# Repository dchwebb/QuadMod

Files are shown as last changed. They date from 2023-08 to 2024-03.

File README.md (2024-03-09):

# Quadmod
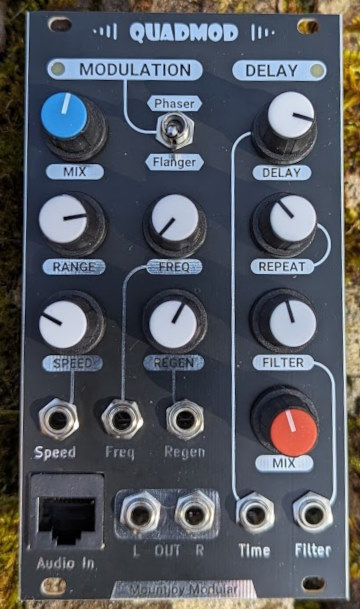
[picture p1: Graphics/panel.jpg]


Quadmod
--------

Quadmod is a Eurorack modular four channel effect module. A modulation section allows either phasing or flanging followed by a delay. As part of the Mountjoy Modular polyphonic range the module uses a series of intermodulation paths to convert a four channel input to a stereo output.

### Phaser
The phaser uses 4 (configurable up to 16) all pass filters to create the phasing effect. Each channel's all pass filter is 45° out of phase with the last. The regeneration (feedback) control progressively mixes one channel to the next to widen the stereo spectrum.

### Flanger
The flanger uses multiple short modulated delays to create a flanger/chorus effect. The delay times are modulated with a 45° phase shift from channel to channel. A wide option (on by default) mixes a further 180° phase shifted version of each channel's signal to the next channel.

Technical
---------

Quadmod uses an STM32563 microcontroller which controls a four channel Audio Codec (AsahiKasei AK4619) using SPI for configuration and SAI (Serial Ausio Interface) peripheral to manage the 4 in and 4 out I2S audio streams. The microcontroller reads the front panel controls with internal 12 bit ADCs.

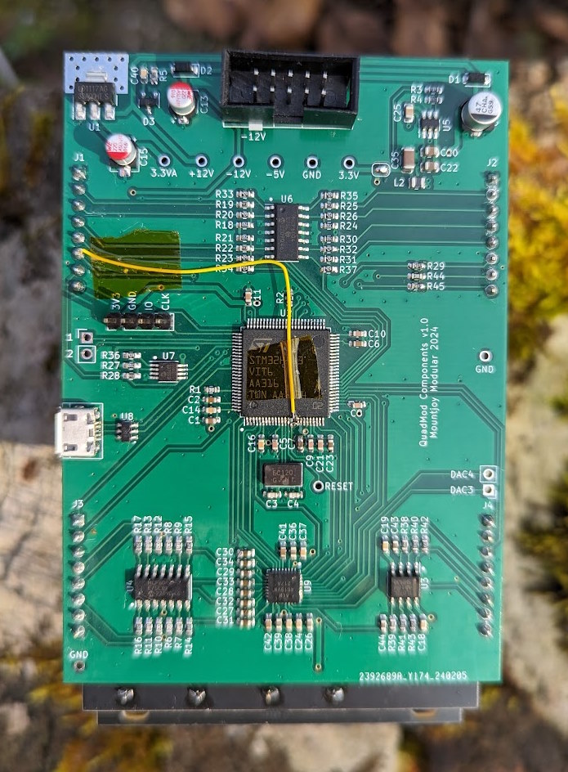
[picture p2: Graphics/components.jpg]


A USB socket is provided for serial configuration and a web editor using WebSerial provides a UI for editing settings. Three LEDs are controlled with PWM from the MCU to indicate modulation LFO rates and delay times.

Construction is a sandwich of three PCBs with a component board, a controls board and a panel. PCBs designed in Kicad v7.

[Components schematic](https://raw.githubusercontent.com/dchwebb/Quadmod/master/Hardware/Quadmod_Components.pdf)

[Controls schematic](https://raw.githubusercontent.com/dchwebb/Quadmod/master/Hardware/Quadmod_Controls.pdf)

In addition the the Eurorack +/-12V rails (which have polarity protection and filtering) a digital 3.3v rail is supplied using a TI TPS561201 and analog 3.3v is generated with an LM1117-3.3.

Errata
------

Version 1 of the component PCB had microcontroller pins PC0 (SAI2_SD_A) and PC1 (DLY_TIME_POT) flipped.

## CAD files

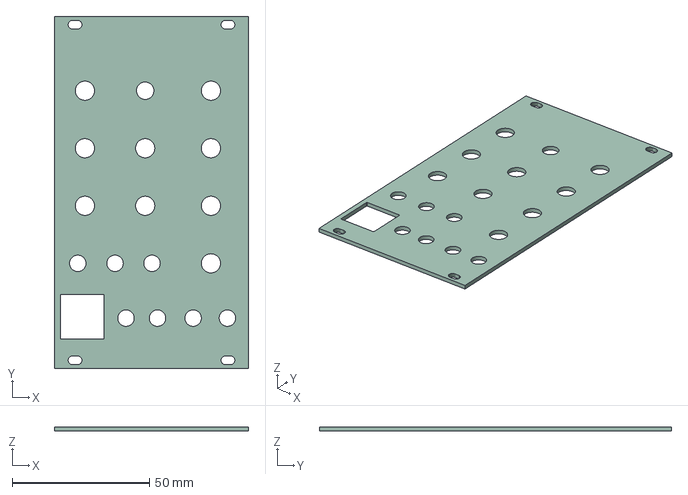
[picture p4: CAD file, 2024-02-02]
Hardware/QuadMod_Panel.step
70.8 x 128.5 x 1.60 mm

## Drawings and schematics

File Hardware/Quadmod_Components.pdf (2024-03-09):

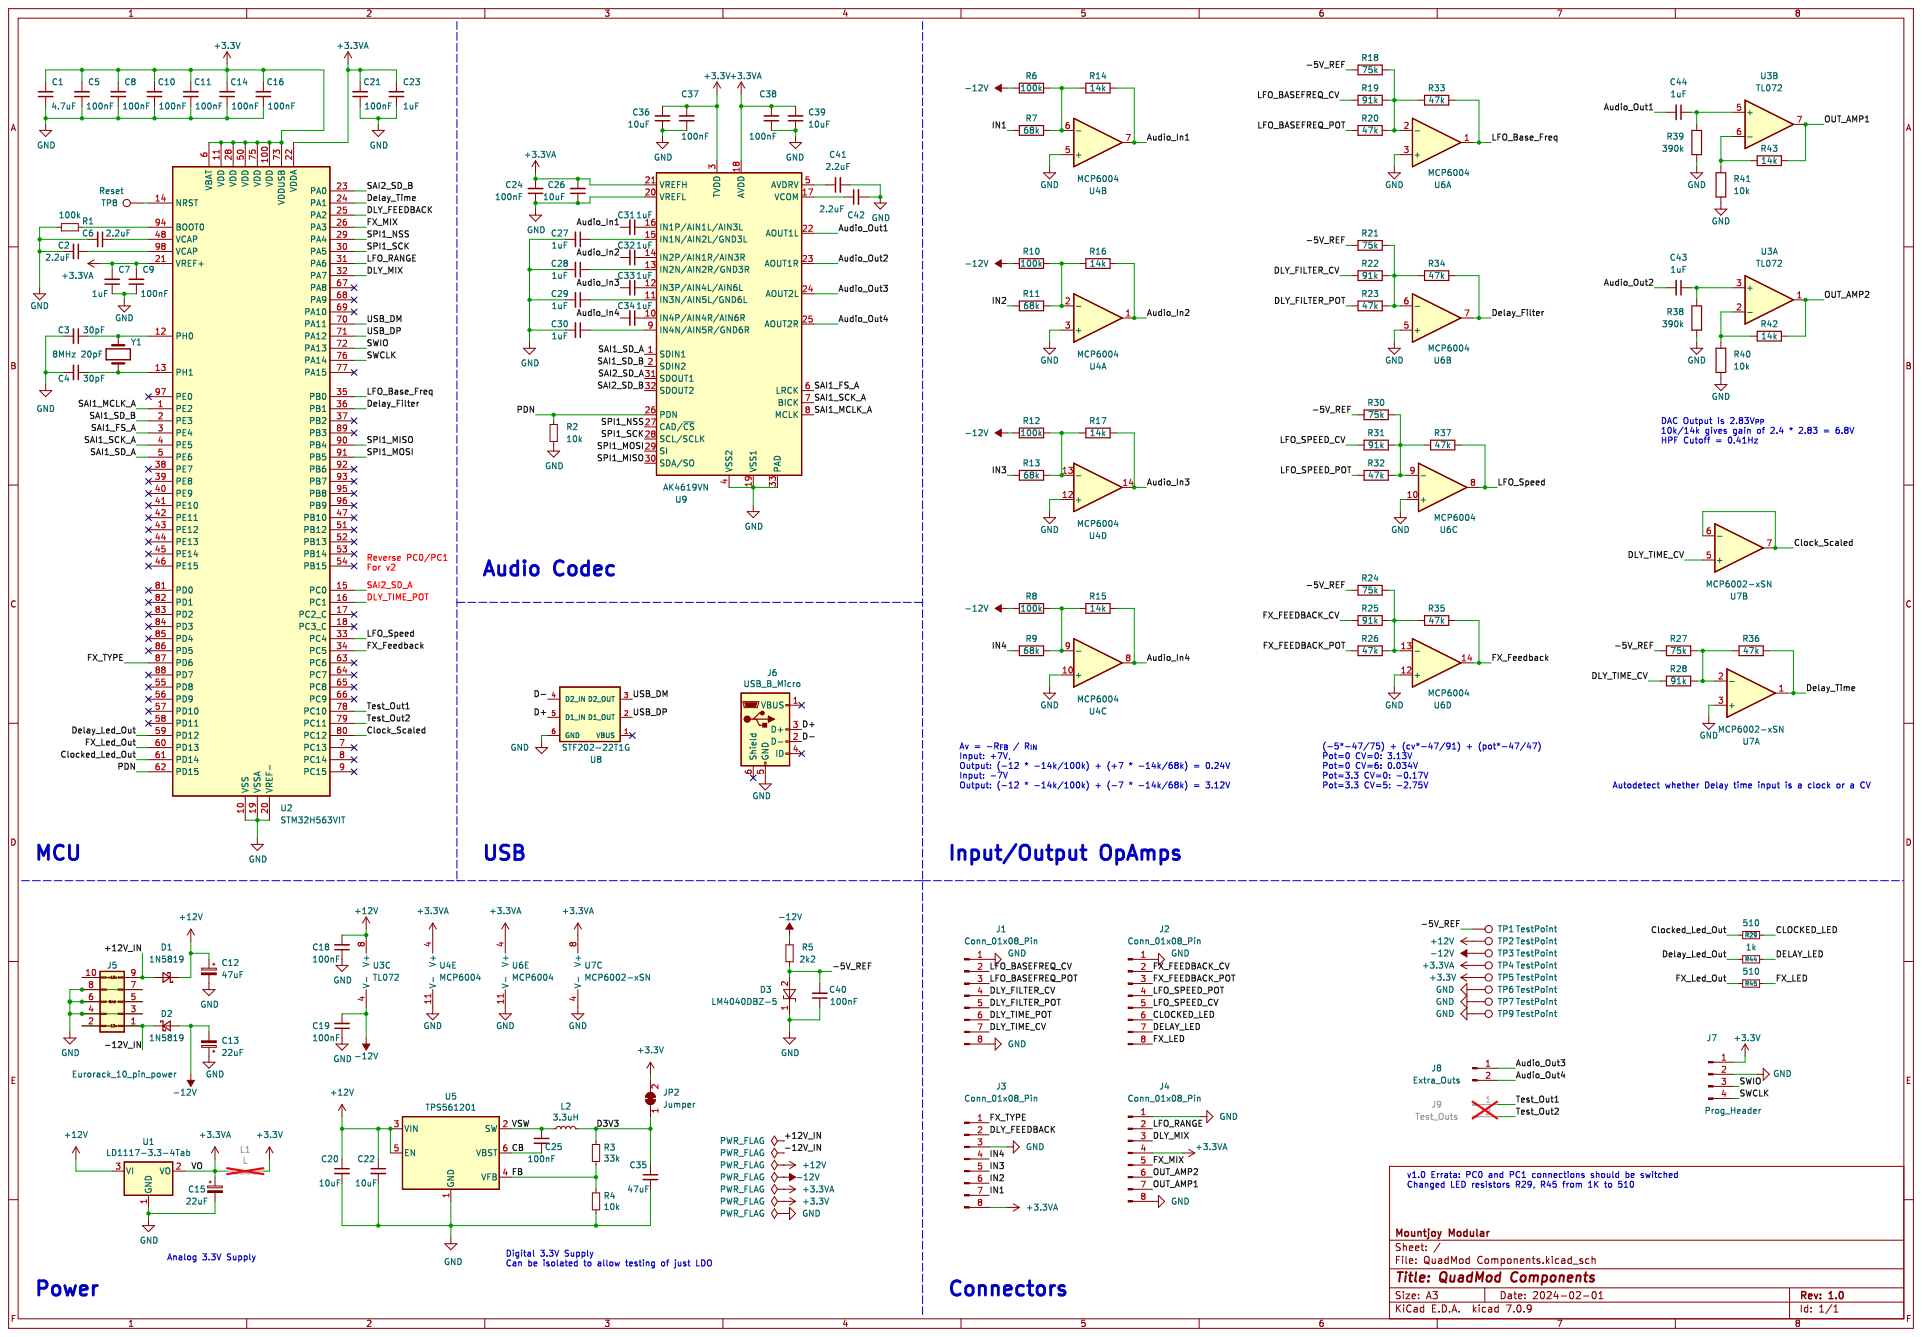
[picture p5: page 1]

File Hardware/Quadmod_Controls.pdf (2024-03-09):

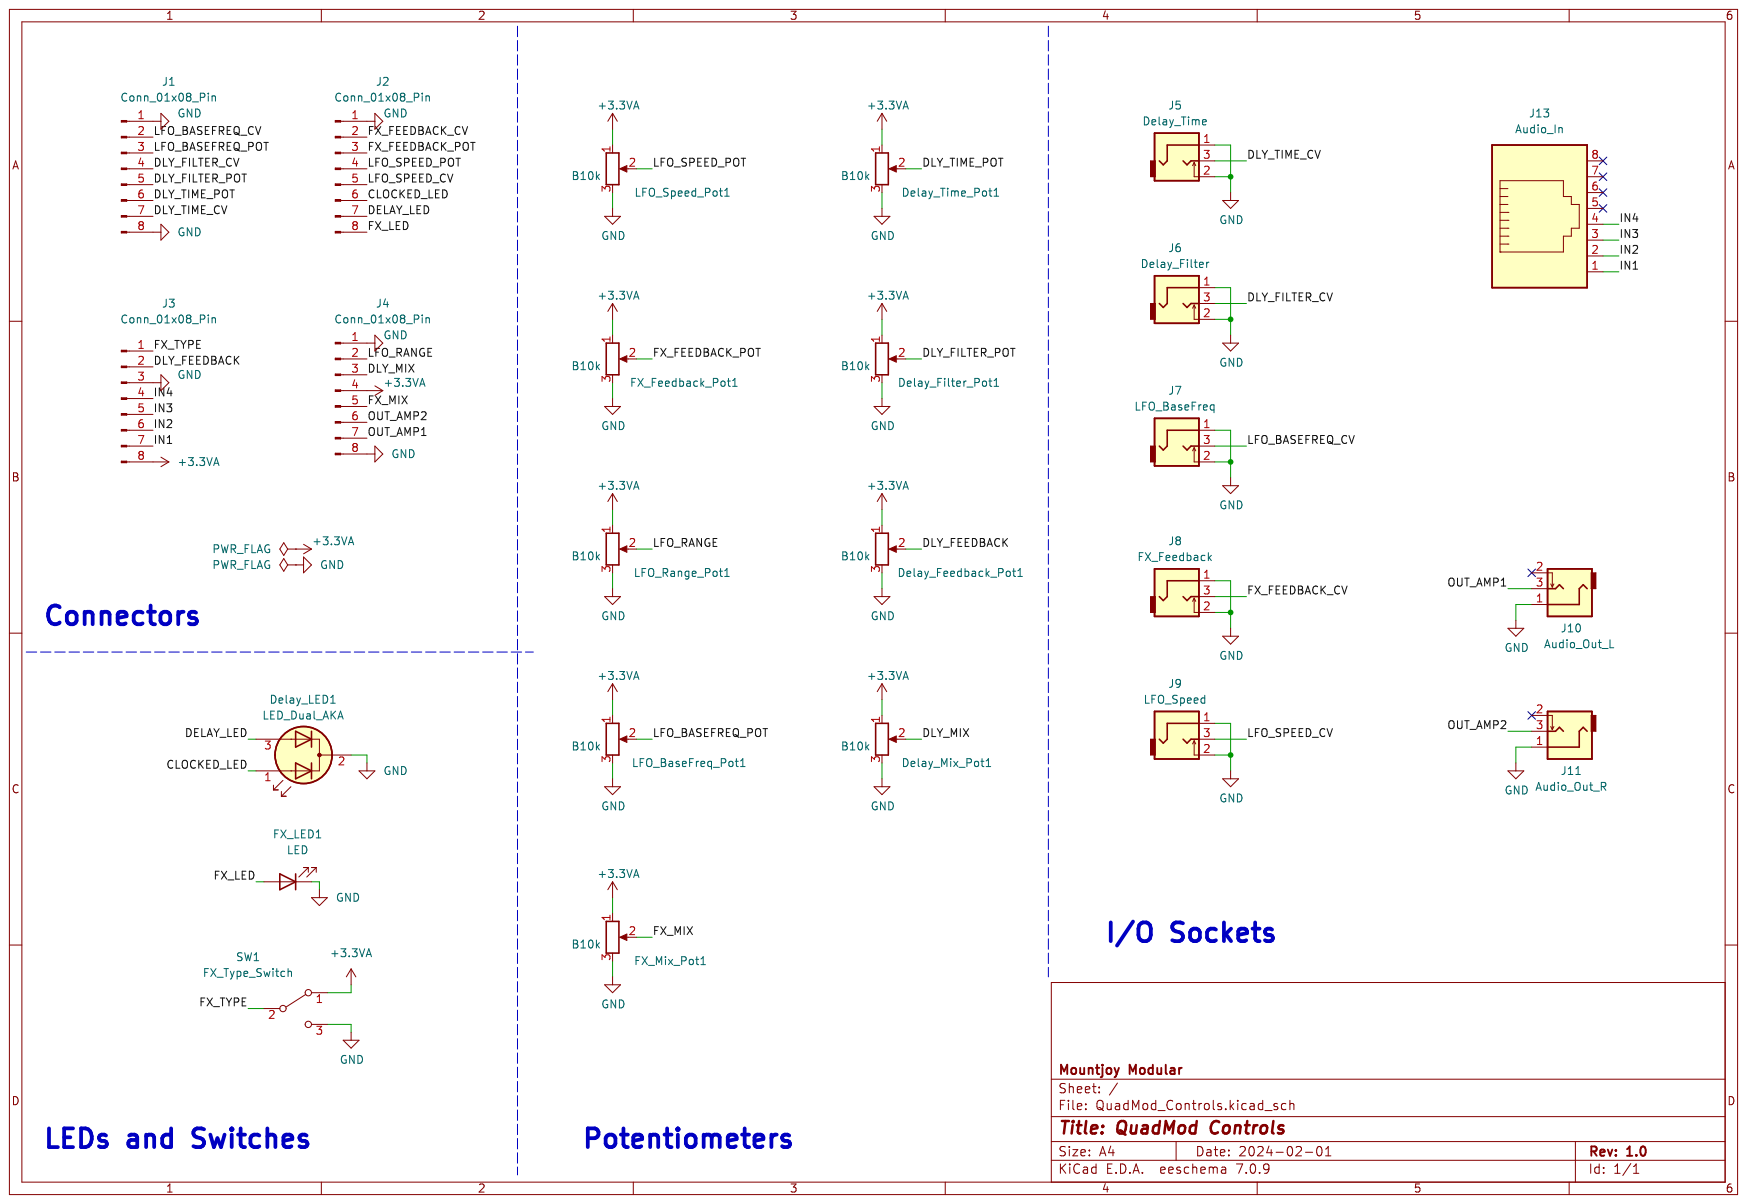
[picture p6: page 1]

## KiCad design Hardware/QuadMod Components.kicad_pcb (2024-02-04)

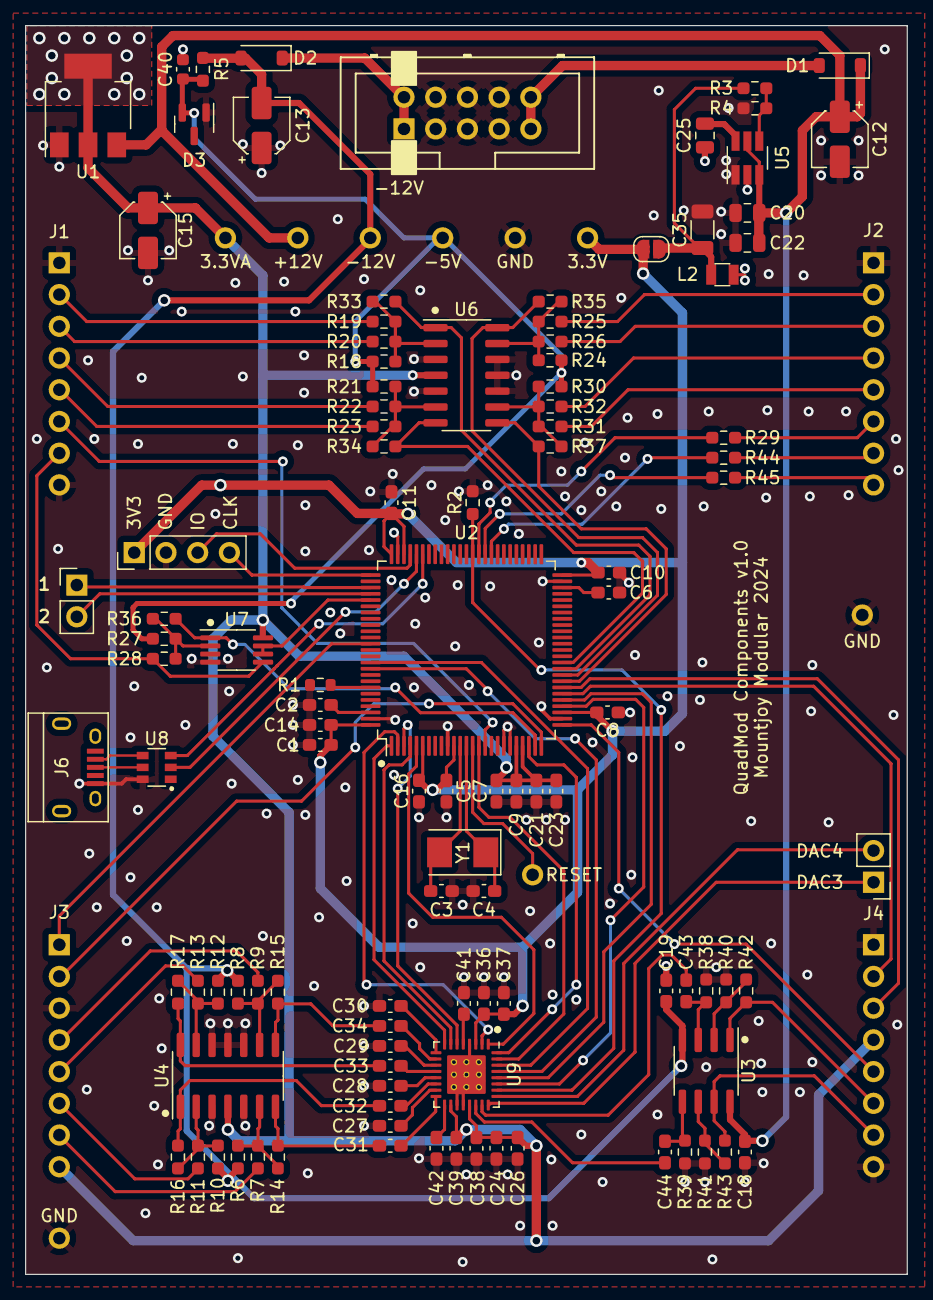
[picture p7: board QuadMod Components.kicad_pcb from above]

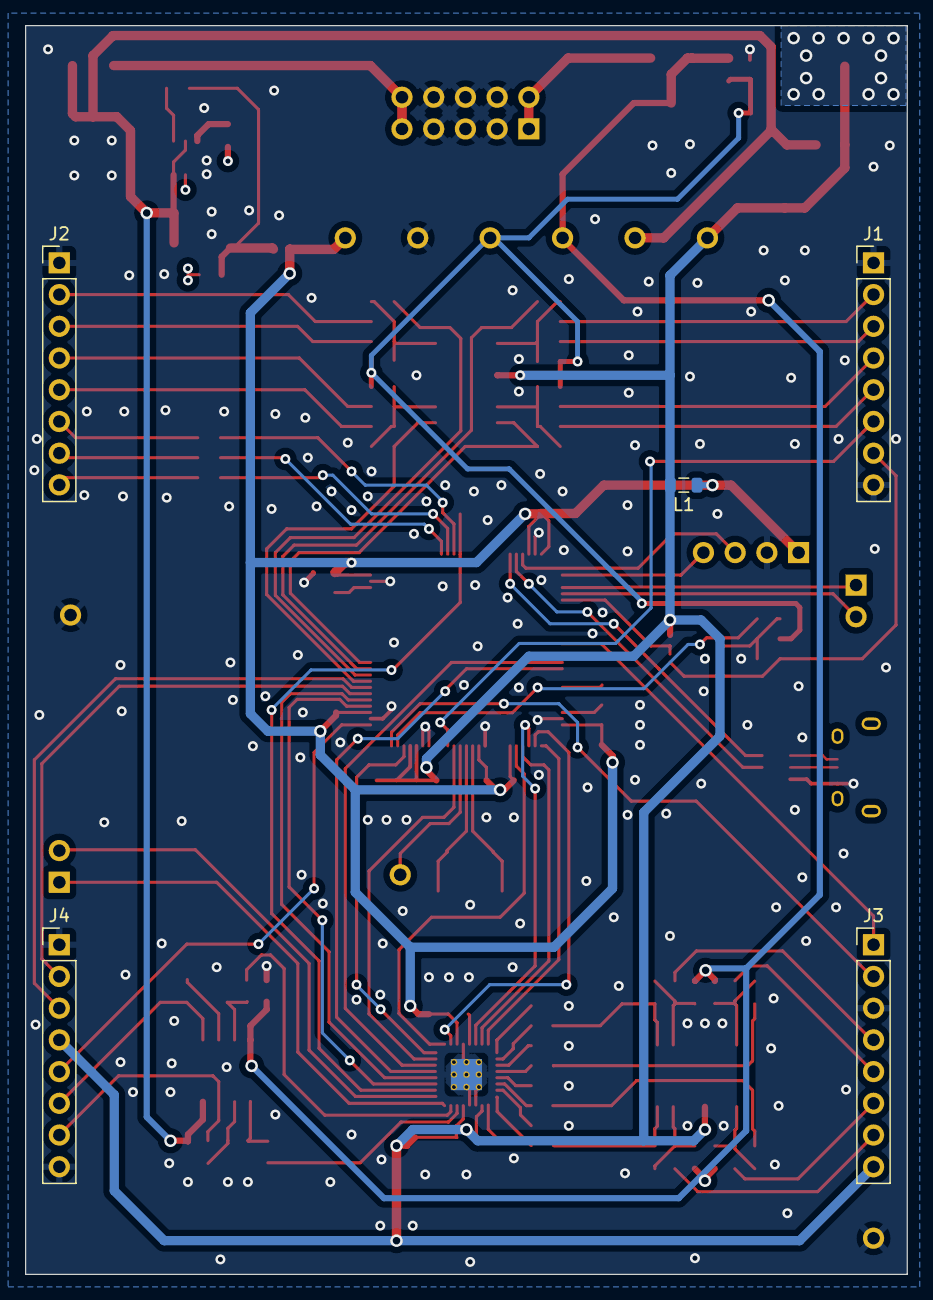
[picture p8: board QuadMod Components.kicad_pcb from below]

Board: 4 copper layers, 70.6 x 100.0 mm, 122 parts (5 on the bottom side), 102 nets.

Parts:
C1: 4.7uF; C_0603_1608Metric_Pad1.08x0.95mm_HandSolder
C2, C6, C41, C42: 2.2uF; C_0603_1608Metric_Pad1.08x0.95mm_HandSolder
C3, C4: 30pF; C_0603_1608Metric_Pad1.08x0.95mm_HandSolder
C5, C8, C9, C10, C11, C14, C16, C18, C19, C21, C24, C37, C38: 100nF; C_0603_1608Metric_Pad1.08x0.95mm_HandSolder
C7, C23, C27, C28, C29, C30, C31, C32, C33, C34, C43, C44: 1uF; C_0603_1608Metric_Pad1.08x0.95mm_HandSolder
C12: 47uF; CP_Elec_4x5.8
C13, C15: 22uF; CP_Elec_4x5.8
C20, C22: 10uF; C_0805_2012Metric
C25: 100nF; C_0805_2012Metric
C26, C36, C39: 10uF; C_0603_1608Metric_Pad1.08x0.95mm_HandSolder
C35: 47uF; R_1206_3216Metric
C40: 100nF; C_0603_1608Metric
D1, D2: 1N5819; D_SOD-123
D3: LM4040DBZ-5; SOT-23
J1, J2, J3, J4: Conn_01x08_Pin; PinHeader_1x08_P2.54mm_Vertical
J5: Eurorack_10_pin_power; Eurorack_10_pin_header
J6: USB_B_Micro; USB_Micro-B_Amphenol
J7: Prog_Header; PinHeader_1x04_P2.54mm_Vertical
J8: Extra_Outs; PinHeader_1x02_P2.54mm_Vertical
J9: Test_Outs; PinHeader_1x02_P2.54mm_Vertical
JP2: Jumper; SolderJumper-2_P1.3mm_Open_RoundedPad1.0x1.5mm
L1: L; L_0805_2012Metric
L2: 3.3uH; L_0806
R1: 100k; R_0603_1608Metric
R2, R4, R40, R41: 10k; R_0603_1608Metric_Pad0.98x0.95mm_HandSolder
R3: 33k; R_0603_1608Metric_Pad0.98x0.95mm_HandSolder
R5: 2k2; R_0603_1608Metric_Pad0.98x0.95mm_HandSolder
R6, R8, R10, R12: 100k; R_0603_1608Metric_Pad0.98x0.95mm_HandSolder
R7, R9, R11, R13: 68k; R_0603_1608Metric_Pad0.98x0.95mm_HandSolder
R14, R15, R16, R17, R42, R43: 14k; R_0603_1608Metric_Pad0.98x0.95mm_HandSolder
R18, R21, R24, R27, R30: 75k; R_0603_1608Metric_Pad0.98x0.95mm_HandSolder
R19, R22, R25, R28, R31: 91k; R_0603_1608Metric_Pad0.98x0.95mm_HandSolder
R20, R23, R26, R32, R33, R34, R35, R36, R37: 47k; R_0603_1608Metric_Pad0.98x0.95mm_HandSolder
R29, R44, R45: 1k; R_0603_1608Metric_Pad0.98x0.95mm_HandSolder
R38, R39: 390k; R_0603_1608Metric_Pad0.98x0.95mm_HandSolder
TP1, TP2, TP3, TP4, TP5, TP6, TP7, TP9: TestPoint; 1mm_Test_Point
TP8: Reset; 1mm_Test_Point
U1: LD1117-3.3-4Tab; SOT-223-3_TabPin2
U2: STM32H563VIT; LQFP-100_14x14mm_P0.5mm
U3: TL072; SOIC-8_3.9x4.9mm_P1.27mm
U4, U6: MCP6004; SO-14_3.9x8.65mm_P1.27mm
U5: TPS561201; SOT-23-6_Handsoldering
U7: MCP6002-xSN; MSOP-8_3x3mm_P0.65mm
U8: STF202-22T1G
U9: AK4619VN; QFN-32-1EP_5x5mm_P0.5mm_EP3.1x3.1mm_ThermalVias
Y1: 8MHz 20pF; Crystal_SMD_5032-2Pin_5.0x3.2mm

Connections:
+3.3V: C1.2, C5.2, C8.2, C10.2, C11.2, C14.2, C16.2, C36.2, C37.2, J7.1, JP2.2 (B), L1.1, TP5.1, U2.6 (VBAT), U2.11 (VDD), U2.28 (VDD), U2.50 (VDD), U2.73 (VDDUSB), U2.75 (VDD), U2.100 (VDD), U9.3 (TVDD)
+3.3VA: C7.2, C9.2, C15.1, C21.2, C23.2, C24.2, C26.2, C38.2, C39.2, J3.8, J4.4, L1.2, TP4.1, U1.2 (VO), U2.21 (VREF+), U2.22 (VDDA), U4.4 (V+), U6.4 (V+), U7.8 (V+), U9.18 (AVDD), U9.21 (VREFH)
+12V: C12.1, C18.2, C20.1, C22.1, D1.1 (K), TP2.1, U1.3 (VI), U3.8 (V+), U5.3 (VIN), U5.5 (EN)
-12V: C13.2, C19.2, D2.2 (A), R5.1, R6.2, R8.2, R10.2, R12.2, TP3.1, U3.4 (V-)
/+12V_IN: D1.2 (A), J5.9, J5.10
/-5V_REF: C40.2, D3.2 (A), R5.2, R18.2, R21.2, R24.2, R27.2, R30.2, TP1.1
/-12V_IN: D2.1 (K), J5.1, J5.2
/Audio_In1: C31.2, R14.1, U4.7
/Audio_In2: C32.2, R16.1, U4.1
/Audio_In3: C33.2, R17.1, U4.14
/Audio_In4: C34.2, R15.1, U4.8
/Audio_Out1: C44.2, U9.22 (AOUT1L)
/Audio_Out2: C43.2, U9.23 (AOUT1R)
/Audio_Out3: J8.1, U9.24 (AOUT2L)
/Audio_Out4: J8.2, U9.25 (AOUT2R)
/CB: C25.2, U5.6 (VBST)
/CLOCKED_LED: J2.6, R29.2
/Clock_Scaled: U2.80 (PC12), U7.6 (-), U7.7
/Clocked_Led_Out: R29.1, U2.61 (PD14)
/D3V3: C35.1, JP2.1 (A), L2.2, R3.1
/D+: J6.3 (D+), U8.5 (D1_IN)
/D-: J6.2 (D-), U8.4 (D2_IN)
/DELAY_LED: J2.7, R44.2
/DLY_FEEDBACK: J3.2, U2.25 (PA2)
/DLY_FILTER_CV: J1.4, R22.2
/DLY_FILTER_POT: J1.5, R23.2
/DLY_MIX: J4.3, U2.32 (PA7)
/DLY_TIME_CV: J1.7, R28.2, U7.5 (+)
/DLY_TIME_POT: J1.6, U2.16 (PC1)
/Delay_Filter: R34.1, U2.36 (PB1), U6.7
/Delay_Led_Out: R44.1, U2.59 (PD12)
/Delay_Time: R36.1, U2.24 (PA1), U7.1
/FB: R3.2, R4.1, U5.4 (VFB)
/FX_FEEDBACK_CV: J2.2, R25.2
/FX_FEEDBACK_POT: J2.3, R26.2
/FX_Feedback: R35.1, U2.34 (PC5), U6.14
/FX_LED: J2.8, R45.2
/FX_Led_Out: R45.1, U2.60 (PD13)
/FX_MIX: J4.5, U2.26 (PA3)
/FX_TYPE: J3.1, U2.87 (PD6)
/IN1: J3.7, R7.2
/IN2: J3.6, R11.2
/IN3: J3.5, R13.2
/IN4: J3.4, R9.2
/LFO_BASEFREQ_CV: J1.2, R19.2
/LFO_BASEFREQ_POT: J1.3, R20.2
/LFO_Base_Freq: R33.1, U2.35 (PB0), U6.1
/LFO_RANGE: J4.2, U2.31 (PA6)
/LFO_SPEED_CV: J2.5, R31.2
/LFO_SPEED_POT: J2.4, R32.2
/LFO_Speed: R37.1, U2.33 (PC4), U6.8
/OUT_AMP1: J4.7, R43.1, U3.7
/OUT_AMP2: J4.6, R42.1, U3.1
/PDN: R2.1, U2.62 (PD15), U9.26 (PDN)
/SAI1_FS_A: U2.3 (PE4), U9.6 (LRCK)
/SAI1_MCLK_A: U2.1 (PE2), U9.8 (MCLK)
/SAI1_SCK_A: U2.4 (PE5), U9.7 (BICK)
/SAI1_SD_A: U2.5 (PE6), U9.1 (SDIN1)
/SAI1_SD_B: U2.2 (PE3), U9.2 (SDIN2)
/SAI2_SD_A: U2.15 (PC0), U9.31 (SDOUT1)
/SAI2_SD_B: U2.23 (PA0), U9.32 (SDOUT2)
/SPI1_MISO: U2.90 (PB4), U9.30 (SDA/SO)
/SPI1_MOSI: U2.91 (PB5), U9.29 (SI)
/SPI1_NSS: U2.29 (PA4), U9.27 (CAD/~CS)
/SPI1_SCK: U2.30 (PA5), U9.28 (SCL/SCLK)
/SWCLK: J7.4, U2.76 (PA14)
/SWIO: J7.3, U2.72 (PA13)
/Test_Out1: J9.1, U2.78 (PC10)
/Test_Out2: J9.2, U2.79 (PC11)
/USB_DM: U2.70 (PA11), U8.3 (D2_OUT)
/USB_DP: U2.71 (PA12), U8.2 (D1_OUT)
/VSW: C25.1, L2.1, U5.2 (SW)
GND: C1.1, C2.2, C3.2, C4.2, C5.1, C6.2, C7.1, C8.1, C9.1, C10.1, C11.1, C12.2, C13.1, C14.1, C15.2, C16.1, C18.1, C19.1, C20.2, C21.1, C22.2, C23.1, C24.1, C26.1, C27.2, C28.2, C29.2, C30.2, C35.2, C36.1, C37.1, C38.1, C39.1, C40.1, C41.2, C42.2, D3.1 (K), J1.1, J1.8, J2.1, J3.3, J4.1, J4.8, J5.3, J5.4, J5.5, J5.6, J5.7, J5.8, J6.5 (GND), J7.2, R1.1, R2.2, R4.2, R38.2, R39.2, R40.2, R41.2, TP6.1, TP7.1, TP9.1, U1.1 (GND), U2.10 (VSS), U2.19 (VSSA), U2.20 (VREF-), U2.27 (VSS), U2.49 (VSS), U2.74 (VSS), U2.99 (VSS), U4.3 (+), U4.5 (+), U4.10 (+), U4.11 (V-), U4.12 (+), U5.1 (GND), U6.3 (+), U6.5 (+), U6.10 (+), U6.11 (V-), U6.12 (+), U7.3 (+), U7.4 (V-), U8.6 (GND), U9.4 (VSS2), U9.19 (VSS1), U9.20 (VREFL), U9.33 (PAD)
unnamed: C2.1, U2.98 (VCAP)
unnamed: C6.1, U2.48 (VCAP)
unnamed: R1.2, U2.94 (BOOT0)
unnamed: TP8.1, U2.14 (NRST)
unnamed: C3.1, U2.12 (PH0), Y1.2
unnamed: C4.1, U2.13 (PH1), Y1.1
unnamed: C43.1, R38.1, U3.3 (+)
unnamed: R40.1, R42.2, U3.2 (-)
unnamed: C44.1, R39.1, U3.5 (+)
unnamed: R41.1, R43.2, U3.6 (-)
unnamed: R10.1, R11.1, R16.2, U4.2 (-)
unnamed: R6.1, R7.1, R14.2, U4.6 (-)
unnamed: R8.1, R9.1, R15.2, U4.9 (-)
unnamed: R12.1, R13.1, R17.2, U4.13 (-)
unnamed: R18.1, R19.1, R20.1, R33.2, U6.2 (-)
unnamed: R21.1, R22.1, R23.1, R34.2, U6.6 (-)
unnamed: R30.1, R31.1, R32.1, R37.2, U6.9 (-)
unnamed: R24.1, R25.1, R26.1, R35.2, U6.13 (-)
unnamed: R27.1, R28.1, R36.2, U7.2 (-)
unnamed: C41.1, U9.5 (AVDRV)
unnamed: C27.1, U9.15 (IN1N/AIN2L/GND3L)
unnamed: C31.1, U9.16 (IN1P/AIN1L/AIN3L)
unnamed: C28.1, U9.13 (IN2N/AIN2R/GND3R)
unnamed: C32.1, U9.14 (IN2P/AIN1R/AIN3R)
unnamed: C29.1, U9.11 (IN3N/AIN5L/GND6L)
unnamed: C33.1, U9.12 (IN3P/AIN4L/AIN6L)
unnamed: C30.1, U9.9 (IN4N/AIN5R/GND6R)
unnamed: C34.1, U9.10 (IN4P/AIN4R/AIN6R)
unnamed: C42.1, U9.17 (VCOM)

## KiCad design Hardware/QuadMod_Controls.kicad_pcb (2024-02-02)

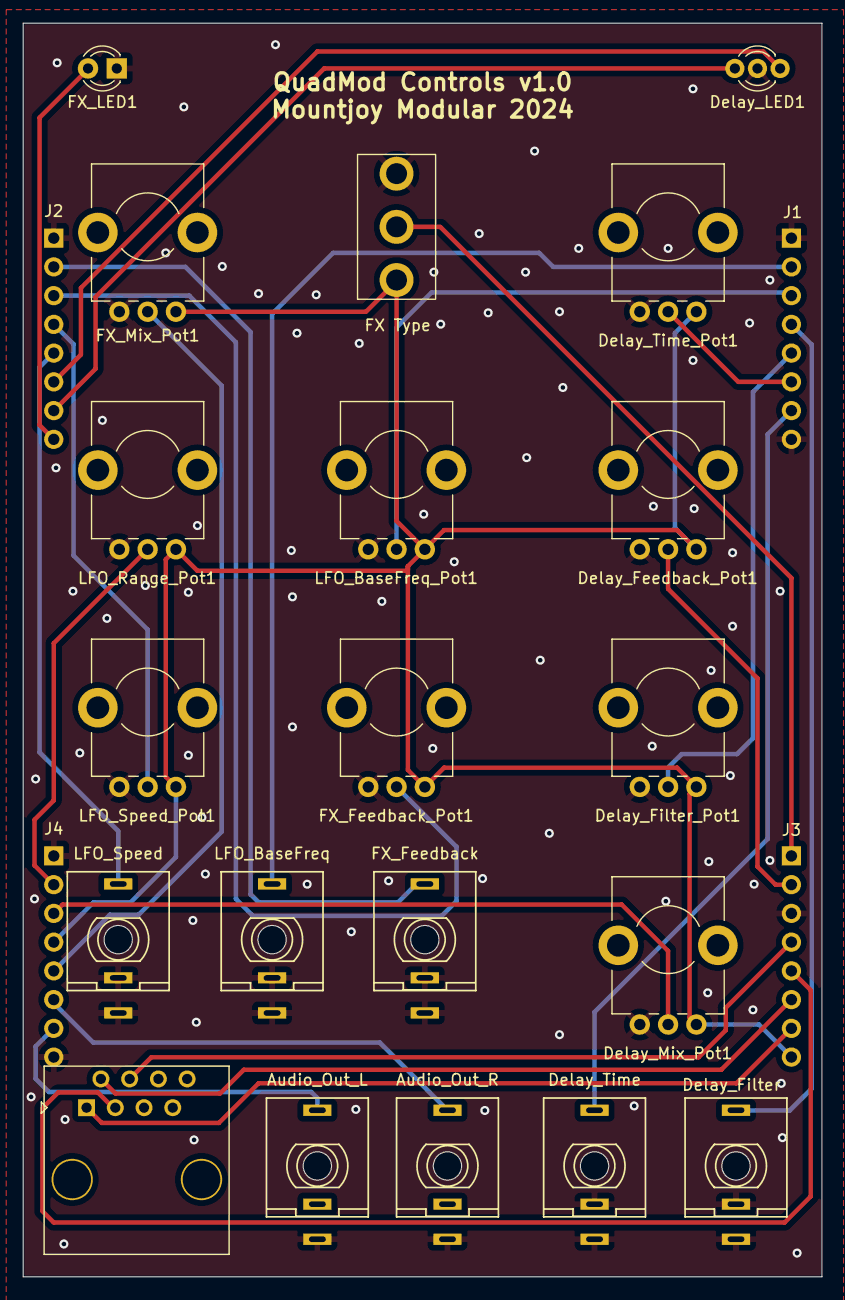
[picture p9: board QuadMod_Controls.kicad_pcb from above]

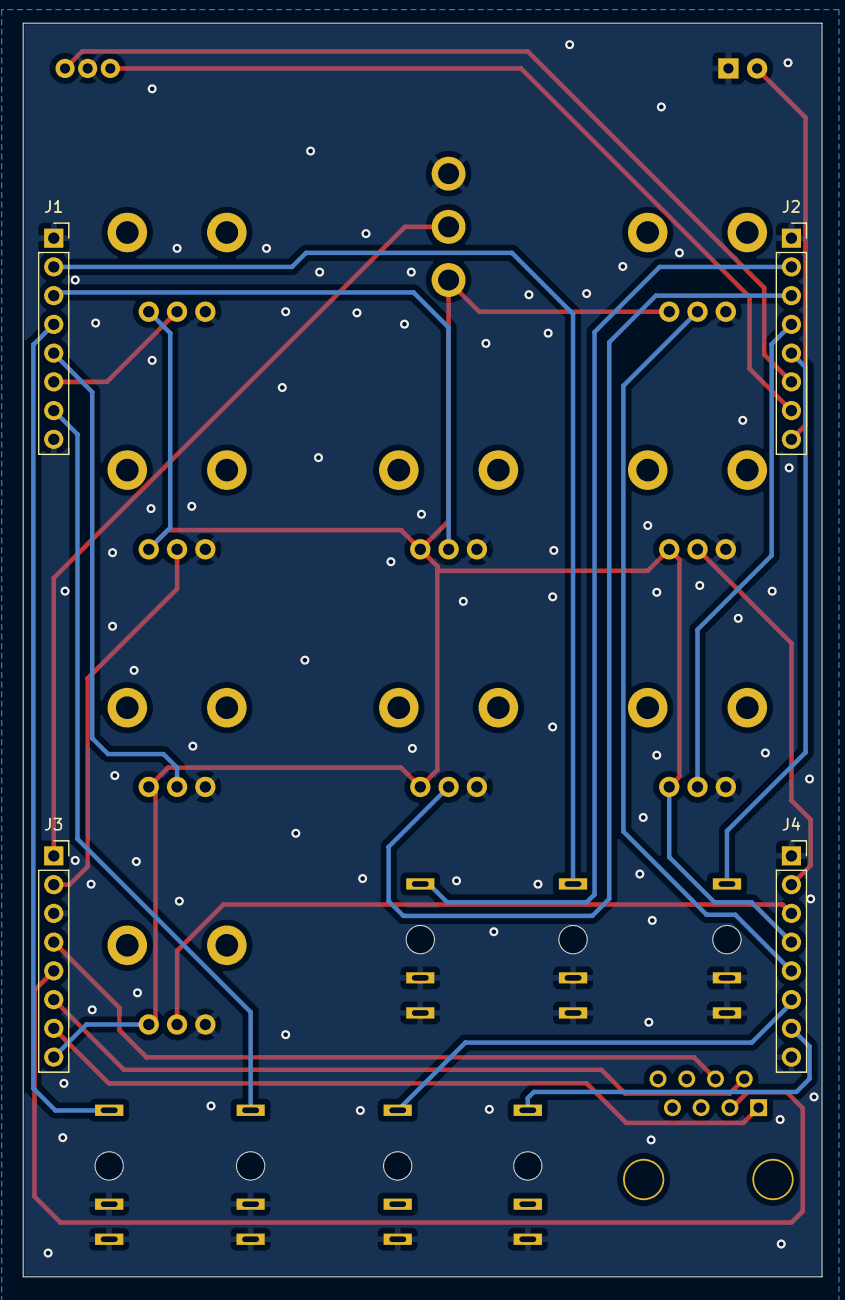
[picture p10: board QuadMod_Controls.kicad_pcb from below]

Board: 2 copper layers, 70.6 x 110.8 mm, 25 parts (4 on the bottom side), 26 nets.

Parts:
Delay_Feedback_Pot1: B10k; Alpha_9mm_Potentiometer_Aligned
Delay_Filter_Pot1: B10k; Alpha_9mm_Potentiometer_Aligned
Delay_LED1: LED_Dual_AKA; LED_D3.0mm-3
Delay_Mix_Pot1: B10k; Alpha_9mm_Potentiometer_Aligned
Delay_Time_Pot1: B10k; Alpha_9mm_Potentiometer_Aligned
FX_Feedback_Pot1: B10k; Alpha_9mm_Potentiometer_Aligned
FX_LED1: LED; LED_D3.0mm
FX_Mix_Pot1: B10k; Alpha_9mm_Potentiometer_Aligned
J1, J2, J3, J4: Conn_01x08_Pin; PinSocket_1x08_P2.54mm_Vertical
J5: Delay_Time; THONKICONN_hole
J6: Delay_Filter; THONKICONN_hole
J7: LFO_BaseFreq; THONKICONN_hole
J8: FX_Feedback; THONKICONN_hole
J9: LFO_Speed; THONKICONN_hole
J10: Audio_Out_L; THONKICONN_hole
J11: Audio_Out_R; THONKICONN_hole
J13: Audio_In; RJ45_Molex_42878-8506
LFO_BaseFreq_Pot1: B10k; Alpha_9mm_Potentiometer_Aligned
LFO_Range_Pot1: B10k; Alpha_9mm_Potentiometer_Aligned
LFO_Speed_Pot1: B10k; Alpha_9mm_Potentiometer_Aligned
PANEL: Panel; 3D_Dummy
SW1: FX_Type_Switch; SPDT_Miniature

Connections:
+3.3VA: Delay_Feedback_Pot1.1, Delay_Filter_Pot1.1, Delay_Mix_Pot1.1, Delay_Time_Pot1.1, FX_Feedback_Pot1.1, FX_Mix_Pot1.1, J3.8, J4.4, LFO_BaseFreq_Pot1.1, LFO_Range_Pot1.1, LFO_Speed_Pot1.1, SW1.1 (A)
/CLOCKED_LED: Delay_LED1.1 (A1), J2.6
/DELAY_LED: Delay_LED1.3 (A2), J2.7
/DLY_FEEDBACK: Delay_Feedback_Pot1.2, J3.2
/DLY_FILTER_CV: J1.4, J6.3
/DLY_FILTER_POT: Delay_Filter_Pot1.2, J1.5
/DLY_MIX: Delay_Mix_Pot1.2, J4.3
/DLY_TIME_CV: J1.7, J5.3
/DLY_TIME_POT: Delay_Time_Pot1.2, J1.6
/FX_FEEDBACK_CV: J2.2, J8.3
/FX_FEEDBACK_POT: FX_Feedback_Pot1.2, J2.3
/FX_LED: FX_LED1.2 (A), J2.8
/FX_MIX: FX_Mix_Pot1.2, J4.5
/FX_TYPE: J3.1, SW1.2 (B)
/IN1: J3.7, J13.1
/IN2: J3.6, J13.2
/IN3: J3.5, J13.3
/IN4: J3.4, J13.4
/LFO_BASEFREQ_CV: J1.2, J7.3
/LFO_BASEFREQ_POT: J1.3, LFO_BaseFreq_Pot1.2
/LFO_RANGE: J4.2, LFO_Range_Pot1.2
/LFO_SPEED_CV: J2.5, J9.3
/LFO_SPEED_POT: J2.4, LFO_Speed_Pot1.2
/OUT_AMP1: J4.7, J10.3
/OUT_AMP2: J4.6, J11.3
GND: Delay_Feedback_Pot1.3, Delay_Filter_Pot1.3, Delay_LED1.2 (K), Delay_Mix_Pot1.3, Delay_Time_Pot1.3, FX_Feedback_Pot1.3, FX_LED1.1 (K), FX_Mix_Pot1.3, J1.1, J1.8, J2.1, J3.3, J4.1, J4.8, J5.1, J5.2, J6.1, J6.2, J7.1, J7.2, J8.1, J8.2, J9.1, J9.2, J10.1, J11.1, LFO_BaseFreq_Pot1.3, LFO_Range_Pot1.3, LFO_Speed_Pot1.3, SW1.3 (C)

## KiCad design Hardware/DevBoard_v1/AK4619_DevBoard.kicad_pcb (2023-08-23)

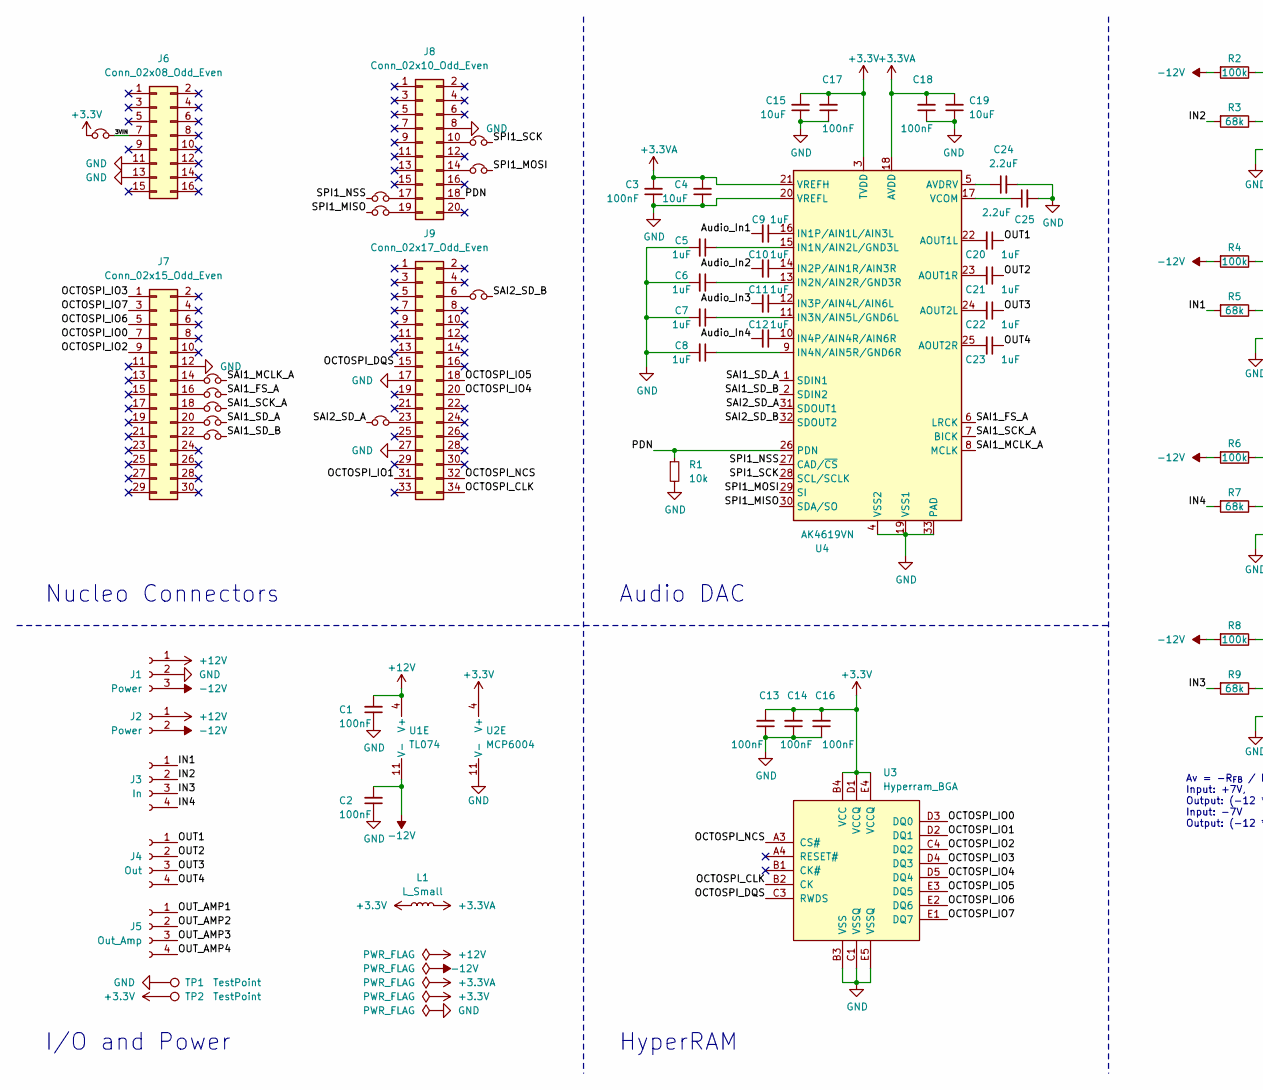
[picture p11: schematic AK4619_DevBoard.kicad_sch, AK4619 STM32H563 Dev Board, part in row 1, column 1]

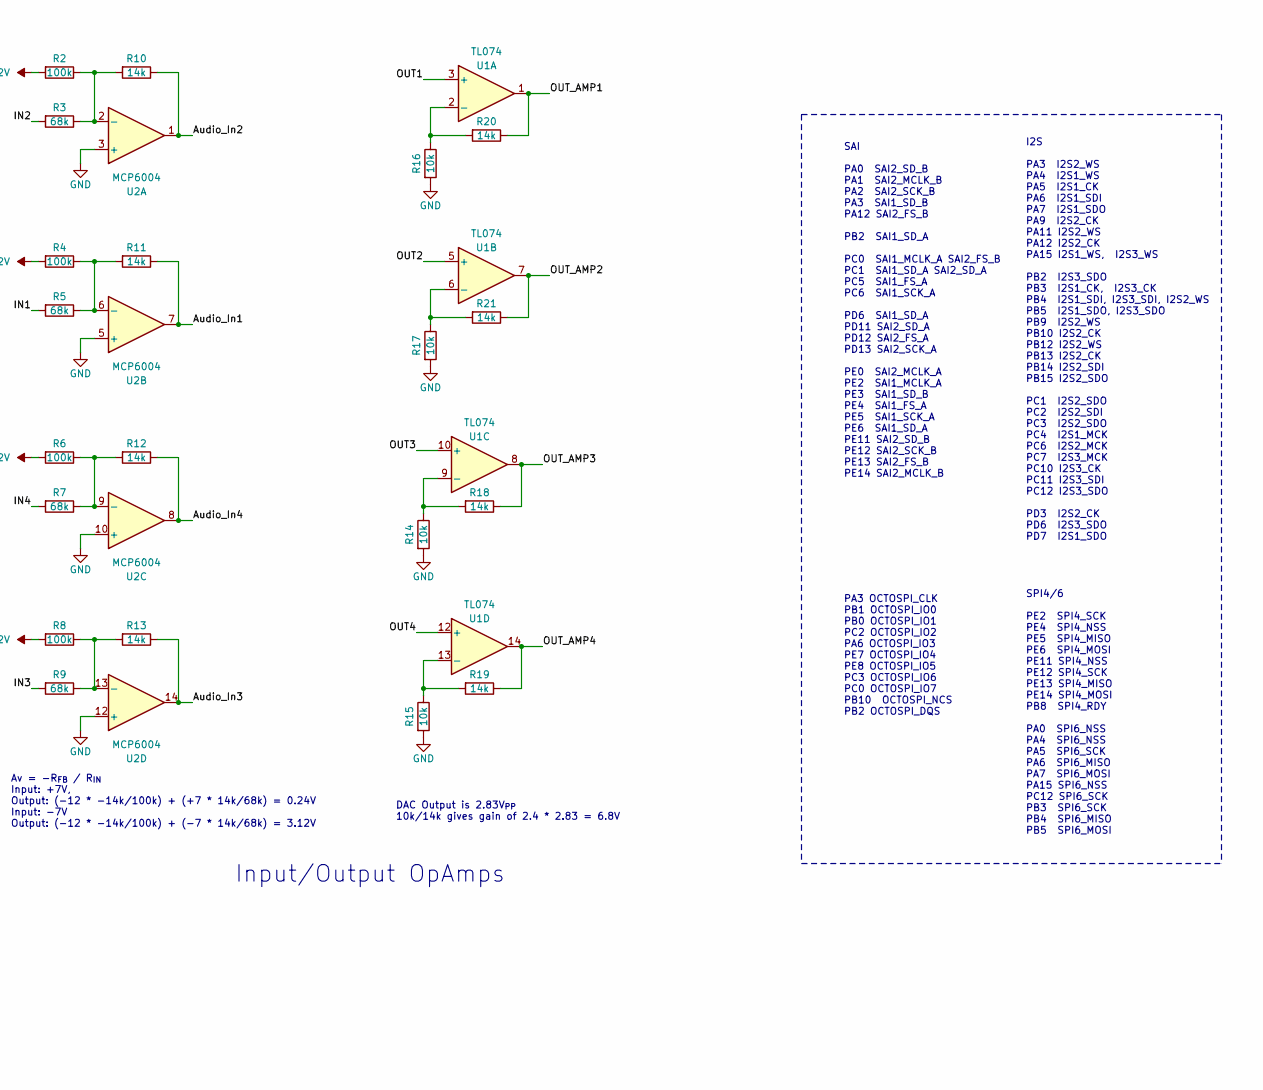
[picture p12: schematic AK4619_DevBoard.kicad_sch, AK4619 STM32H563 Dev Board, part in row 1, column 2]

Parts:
C1, C2, C3, C13, C14, C16, C17, C18: 100nF; C_0603_1608Metric_Pad1.08x0.95mm_HandSolder
C4, C15, C19: 10uF; C_0603_1608Metric_Pad1.08x0.95mm_HandSolder
C5, C6, C7, C8, C9, C10, C11, C12, C20, C21, C22, C23: 1uF; C_0603_1608Metric_Pad1.08x0.95mm_HandSolder
C24, C25: 2.2uF; C_0603_1608Metric_Pad1.08x0.95mm_HandSolder
J1: Power; PinSocket_1x03_P2.54mm_Vertical
J2: Power; PinSocket_1x02_P2.54mm_Vertical
J3: In; PinSocket_1x04_P2.54mm_Vertical
J4: Out; PinSocket_1x04_P2.54mm_Vertical
J5: Out_Amp; PinSocket_1x04_P2.54mm_Vertical
J6: Conn_02x08_Odd_Even; PinHeader_2x08_P2.54mm_Vertical
J7: Conn_02x15_Odd_Even; PinHeader_2x15_P2.54mm_Vertical
J8: Conn_02x10_Odd_Even; PinHeader_2x10_P2.54mm_Vertical
J9: Conn_02x17_Odd_Even; PinHeader_2x17_P2.54mm_Vertical
JP1, JP2, JP3, JP4, JP5, JP6, JP7, JP8, JP9, JP10, JP11, JP12: Jumper_NC_Small; SolderJumper-2_P1.3mm_Bridged_RoundedPad1.0x1.5mm
L1: L_Small; L_0603_1608Metric_Pad1.05x0.95mm_HandSolder
R1: 10k; R_0603_1608Metric_Pad0.98x0.95mm_HandSolder
R2, R4, R6, R8: 100k; R_0603_1608Metric_Pad0.98x0.95mm_HandSolder; Part_Number C4184
R3, R5, R7, R9: 68k; R_0603_1608Metric_Pad0.98x0.95mm_HandSolder; Part_Number C25819
R10, R11, R12, R13, R18, R19, R20, R21: 14k; R_0603_1608Metric_Pad0.98x0.95mm_HandSolder; Part_Number C23212
R14, R15, R16, R17: 10k; R_0603_1608Metric_Pad0.98x0.95mm_HandSolder; Part_Number C23212
TP1, TP2: TestPoint; 1mm_Test_Point
U1: TL074; SO-14_3.9x8.65mm_P1.27mm
U2: MCP6004; SO-14_3.9x8.65mm_P1.27mm
U3: Hyperram_BGA; BGA-24_5x5_6.0x8.0mm
U4: AK4619VN; QFN-32-1EP_5x5mm_P0.5mm_EP3.1x3.1mm_ThermalVias

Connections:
+3.3V: C13.2, C14.2, C15.2, C16.2, C17.2, JP1.1, L1.1, TP2.1, U2.4 (V+), U3.B4 (VCC), U3.D1 (VCCQ), U3.E4 (VCCQ), U4.3 (TVDD)
+3.3VA: C3.2, C4.2, C18.2, C19.2, L1.2, U4.18 (AVDD), U4.21 (VREFH)
+12V: C1.2, J1.1, J2.1, U1.4 (V+)
-12V: C2.2, J1.3, J2.2, R2.2, R4.2, R6.2, R8.2, U1.11 (V-)
/3VIN: J6.7, JP1.2
/Audio_In1: C9.2, R11.1, U2.7
/Audio_In2: C10.2, R10.1, U2.1
/Audio_In3: C11.2, R13.1, U2.14
/Audio_In4: C12.2, R12.1, U2.8
/IN1: J3.1, R5.2
/IN2: J3.2, R3.2
/IN3: J3.3, R9.2
/IN4: J3.4, R7.2
/OCTOSPI_CLK: J9.34, U3.B2 (CK)
/OCTOSPI_DQS: J9.15, U3.C3 (RWDS)
/OCTOSPI_IO0: J7.7, U3.D3 (DQ0)
/OCTOSPI_IO1: J9.31, U3.D2 (DQ1)
/OCTOSPI_IO2: J7.9, U3.C4 (DQ2)
/OCTOSPI_IO3: J7.1, U3.D4 (DQ3)
/OCTOSPI_IO4: J9.20, U3.D5 (DQ4)
/OCTOSPI_IO5: J9.18, U3.E3 (DQ5)
/OCTOSPI_IO6: J7.5, U3.E2 (DQ6)
/OCTOSPI_IO7: J7.3, U3.E1 (DQ7)
/OCTOSPI_NCS: J9.32, U3.A3 (CS#)
/OUT1: C20.1, J4.1, U1.3 (+)
/OUT2: C21.1, J4.2, U1.5 (+)
/OUT3: C22.1, J4.3, U1.10 (+)
/OUT4: C23.1, J4.4, U1.12 (+)
/OUT_AMP1: J5.1, R20.1, U1.1
/OUT_AMP2: J5.2, R21.1, U1.7
/OUT_AMP3: J5.3, R18.1, U1.8
/OUT_AMP4: J5.4, R19.1, U1.14
/PDN: J8.18, R1.1, U4.26 (PDN)
/SAI1_FS_A: JP3.2, U4.6 (LRCK)
/SAI1_MCLK_A: JP2.2, U4.8 (MCLK)
/SAI1_SCK_A: JP4.2, U4.7 (BICK)
/SAI1_SD_A: JP5.2, U4.1 (SDIN1)
/SAI1_SD_B: JP6.2, U4.2 (SDIN2)
/SAI2_SD_A: JP9.1, U4.31 (SDOUT1)
/SAI2_SD_B: JP12.2, U4.32 (SDOUT2)
/SPI1_MISO: JP8.1, U4.30 (SDA/SO)
/SPI1_MOSI: JP11.2, U4.29 (SI)
/SPI1_NSS: JP7.1, U4.27 (CAD/~CS)
/SPI1_SCK: JP10.2, U4.28 (SCL/SCLK)
GND: C1.1, C2.1, C3.1, C4.1, C5.2, C6.2, C7.2, C8.2, C13.1, C14.1, C15.1, C16.1, C17.1, C18.1, C19.1, C24.2, C25.2, J1.2, J6.11, J6.13, J7.12, J8.8, J9.17, J9.27, R1.2, R14.2, R15.2, R16.2, R17.2, TP1.1, U2.3 (+), U2.5 (+), U2.10 (+), U2.11 (V-), U2.12 (+), U3.B3 (VSS), U3.C1 (VSSQ), U3.E5 (VSSQ), U4.4 (VSS2), U4.19 (VSS1), U4.20 (VREFL), U4.33 (PAD)
unnamed: J7.14, JP2.1
unnamed: J7.16, JP3.1
unnamed: J7.18, JP4.1
unnamed: J7.20, JP5.1
unnamed: J7.22, JP6.1
unnamed: J8.10, JP10.1
unnamed: J8.14, JP11.1
unnamed: J8.17, JP7.2
unnamed: J8.19, JP8.2
unnamed: J9.6, JP12.1
unnamed: J9.23, JP9.2
unnamed: R16.1, R20.2, U1.2 (-)
unnamed: R17.1, R21.2, U1.6 (-)
unnamed: R14.1, R18.2, U1.9 (-)
unnamed: R15.1, R19.2, U1.13 (-)
unnamed: R2.1, R3.1, R10.2, U2.2 (-)
unnamed: R4.1, R5.1, R11.2, U2.6 (-)
unnamed: R6.1, R7.1, R12.2, U2.9 (-)
unnamed: R8.1, R9.1, R13.2, U2.13 (-)
unnamed: C20.2, U4.22 (AOUT1L)
unnamed: C21.2, U4.23 (AOUT1R)
unnamed: C22.2, U4.24 (AOUT2L)
unnamed: C23.2, U4.25 (AOUT2R)
unnamed: C24.1, U4.5 (AVDRV)
unnamed: C5.1, U4.15 (IN1N/AIN2L/GND3L)
unnamed: C9.1, U4.16 (IN1P/AIN1L/AIN3L)
unnamed: C6.1, U4.13 (IN2N/AIN2R/GND3R)
unnamed: C10.1, U4.14 (IN2P/AIN1R/AIN3R)
unnamed: C7.1, U4.11 (IN3N/AIN5L/GND6L)
unnamed: C11.1, U4.12 (IN3P/AIN4L/AIN6L)
unnamed: C8.1, U4.9 (IN4N/AIN5R/GND6R)
unnamed: C12.1, U4.10 (IN4P/AIN4R/AIN6R)
unnamed: C25.1, U4.17 (VCOM)

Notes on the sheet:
HyperRAM
PA3 OCTOSPI_CLK PB1 OCTOSPI_IO0 PB0 OCTOSPI_IO1 PC2 OCTOSPI_IO2 PA6 OCTOSPI_IO3 PE7 OCTOSPI_IO4 PE8 OCTOSPI_IO5 PC3 OCTOSPI_IO6 PC0 OCTOSPI_IO7 PB10 OCTOSPI_NCS PB2 OCTOSPI_DQS
Nucleo Connectors
I2S PA3 I2S2_WS PA4 I2S1_WS PA5 I2S1_CK PA6 I2S1_SDI PA7 I2S1_SDO PA9 I2S2_CK PA11 I2S2_WS PA12 I2S2_CK PA15 I2S1_WS, I2S3_WS PB2 I2S3_SDO PB3 I2S1_CK, I2S3_CK PB4 I2S1_SDI, I2S3_SDI, I2S2_WS PB5 I2S1_SDO, I2S3_SDO PB9 I2S2_WS PB10 I2S2_CK PB12 I2S2_WS PB13 I2S2_CK PB14 I2S2_SDI PB15 I2S2_SDO PC1 I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
Input/Output OpAmps
Audio DAC
I/O and Power
Av = -R_{FB} / R_{IN} Input: +7V, Output: (-12 * -14k/100k) + (+7 * 14k/68k) = 0.24V Input: -7V Output: (-12 * -14k/100k) + (-7 * 14k/68k) = 3.12V
SAI PA0 SAI2_SD_B PA1 SAI2_MCLK_B PA2 SAI2_SCK_B PA3 SAI1_SD_B PA12 SAI2_FS_B PB2 SAI1_SD_A PC0 SAI1_MCLK_A SAI2_FS_B PC1 SAI1_SD_A SAI2_SD_A PC5 SAI1_FS_A PC6 SAI1_SCK_A PD6 SAI1_SD_A PD11 SAI2_SD_A PD12 SAI2_FS_A PD13 SAI2_SCK_A PE0 SAI2_MCLK_A PE2 SAI1_MCLK_A PE3 SAI1_SD_B PE4 SAI1_FS_A PE5 SAI1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
SPI4/6 PE2 SPI4_SCK PE4 SPI4_NSS PE5 SPI4_MISO PE6 SPI4_MOSI PE11 SPI4_NSS PE12 SPI4_SCK PE13 SPI4_MISO PE14 SPI4_MOSI PB8 SPI4_RDY PA0 SPI6_NSS PA4 SPI6_NSS PA5 SPI6_SCK PA6 SPI6_MISO PA7 SPI6_MOSI PA15 SPI6_NSS PC12 SPI6_SCK PB3 SPI6_SCK PB4 SPI6_MISO PB5 SPI6_MOSI
DAC Output is 2.83V_{PP} 10k/14k gives gain of 2.4 * 2.83 = 6.8V

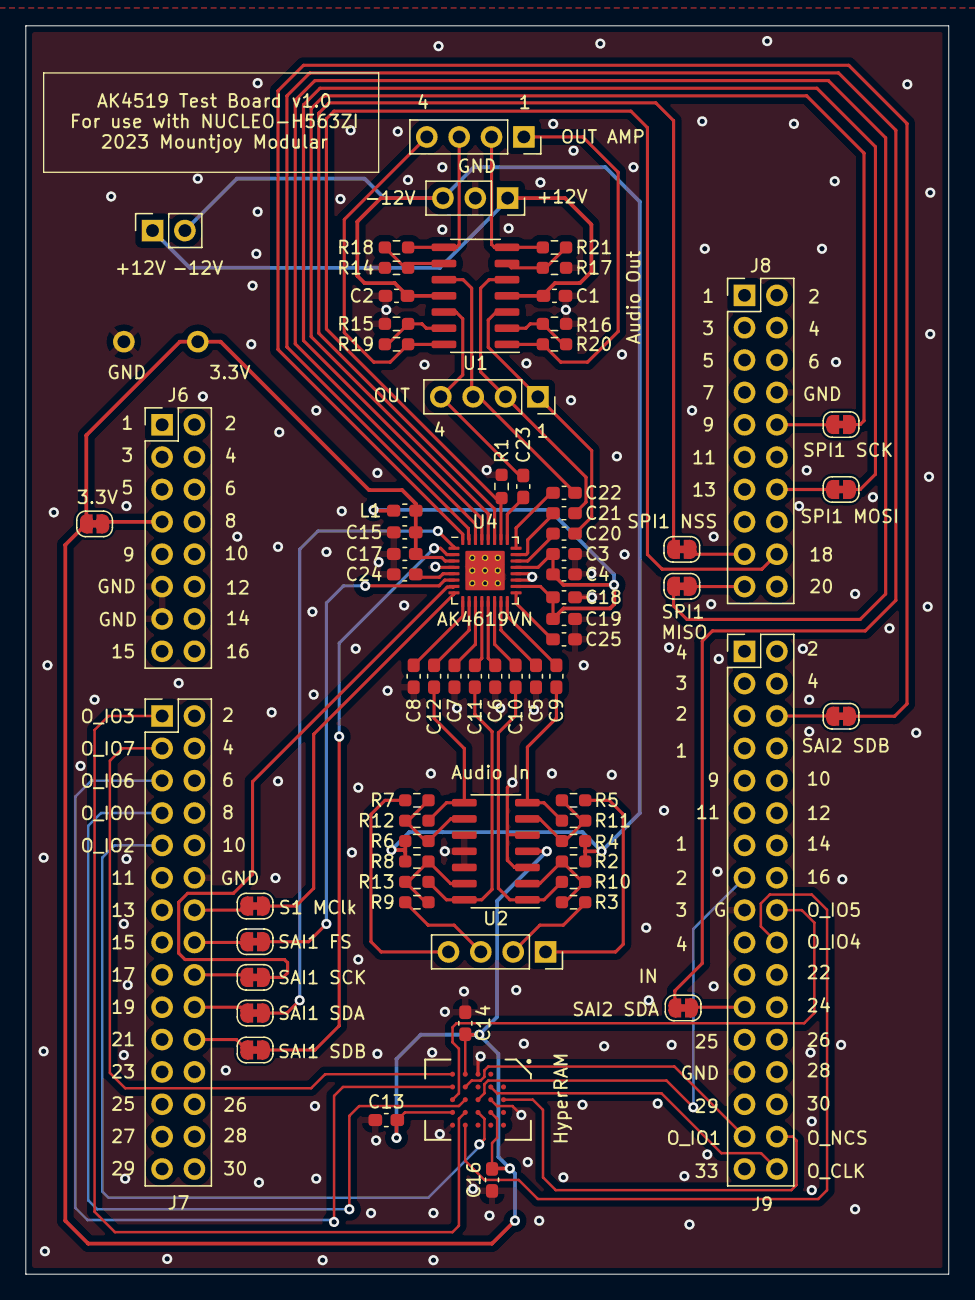
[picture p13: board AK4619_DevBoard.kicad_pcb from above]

Board: 2 copper layers, 72.4 x 98.0 mm, 74 parts (0 on the bottom side), 78 nets.

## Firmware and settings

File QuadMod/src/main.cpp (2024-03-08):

#include "initialisation.h"
#include "USB.h"
#include "AudioCodec.h"
#include "EffectManager.h"
#include "Delay.h"


volatile uint32_t SysTickVal;
volatile uint32_t outputUSB = 0;		// USB debugging
volatile ADCValues adc;

extern "C" {
#include "interrupts.h"
}

/*
	Potential improvements:
	- Config saving (eg flanger wide; phaser filter count etc)
	- CDC allows editing of adc (legacy)
	- USB not working if optimisation set above -O0
	- USB supports MIDI (unused, legacy)
	- UART not tested
 */

extern uint32_t SystemCoreClock;
int main(void)
{
	SystemInit();						// Activates floating point coprocessor and resets clock
	InitSystemClock();					// Configure the clock and PLL
	InitHardware();
	effectManager.EffectType();
	audioCodec.Init();
	usb.InitUSB();

	while (1) {
#if (USB_DEBUG)
		if (SysTickVal - outputUSB > 1000 && (GPIOC->IDR & GPIO_IDR_ID13) == GPIO_IDR_ID13) {
			usb.OutputDebug();
			outputUSB = SysTickVal;
		}
#endif
		usb.cdc.ProcessCommand();

		// When the audio codec has output samples, idle jobs (ie filter recalculation) can be done by the active effect
		if (audioCodec.outputDone) {
			audioCodec.outputDone = false;
			effectManager.IdleJobs();
		}
	}
}

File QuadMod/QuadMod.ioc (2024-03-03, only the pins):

Mcu.UserName=STM32H563VITx
PA0.Signal=ADCx_INP0
PA1.Signal=ADCx_INP1
PA2.Signal=ADCx_INP14
PA4.Signal=SPI1_NSS
PA5.Signal=SPI1_SCK
PA6.Signal=ADCx_INP3
PA7.Signal=ADCx_INP7
PB0.Signal=SharedAnalog_PB0
PB4(NJTRST).Signal=SPI1_MISO
PB5.Signal=SPI1_MOSI
PC1.Signal=ADCx_INP11
PC4.Signal=ADCx_INP4
PC5.Signal=ADCx_INP8
PE2.Signal=SAI1_MCLK_A
PE4.Signal=SAI1_FS_A
PE5.Signal=SAI1_SCK_A
PE6.Signal=SAI1_SD_A
PH0-OSC_IN(PH0).Signal=RCC_OSC_IN
PH1-OSC_OUT(PH1).Signal=RCC_OSC_OUT

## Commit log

2023-07-28 SAI1 correctly outputting 32 bit I2S test pattern
    [initialisation.cpp]
2023-07-28 Started configuring SAI2
    [QuadMod.kicad_sch]
2023-07-30 USB class compiles without errors
    [USB.cpp, USB.h]
2023-08-01 Started laying out Audio Codec Test Board
    [AK4619_DevBoard.kicad_pcb, AK4619_DevBoard.kicad_sch, QuadMod.kicad_sch]
2023-08-02 Added HyperRam to Dev Board
    [AK4619_DevBoard-B_Cu.gbr, AK4619_DevBoard-B_Mask.gbr, AK4619_DevBoard-B_Paste.gbr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]
2023-08-04 Added Input scaling
    [AK4619_DevBoard.kicad_pcb, AK4619_DevBoard.kicad_sch]
2023-08-23 Added Ouput op-amp
    [AK4619_DevBoard.kicad_pcb, AK4619_DevBoard.kicad_sch]
2023-08-23 DevBoard Gerbers ordered
    [AK4619_DevBoard-B_Cu.gbr, AK4619_DevBoard-B_Mask.gbr, AK4619_DevBoard-B_Paste.gbr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]
2023-11-02 Fixed issue getting UID in USB setup routine (using MPU)
    [USB.cpp, initialisation.cpp]
2023-11-02 Implemented SPI to control Audio Codec
2023-11-02 Fixed SPI data send; trying to read back register
    [AudioCodec.cpp]
2023-11-03 Audio codec SPI initialisation and read/write tested working
2023-11-04 Updated SAI FIFO interrupt to prevent underruns
    Test output sine wave
    [AudioCodec.cpp, initialisation.cpp]
2023-11-04 Audio recording working on channel 1 (fixed I2S input clock polarity)
    [AudioCodec.cpp, initialisation.cpp]
2023-11-05 Changed I2S implementation so that output and input signals are sampled on rising edge
2023-11-05 Cleaned up Audio Codec test signal loop-back
    [AK4619_DevBoard.kicad_pcb, AK4619_DevBoard.kicad_sch]
2023-11-05 Changed codec ADC filter to improve latency
    Also added serial support for writing to codec registers
2023-11-09 Fixed crash after writing; data still not being written, however
    [initialisation.cpp]
2023-12-09 Started configuring ADC DMA
2023-12-09 ADC with DMA seems to be working
    Using DMA Linked list to update registers
2023-12-09 Cleaned up ADC/DMA initialisation
2023-12-10 Added tanh limiting to sample output
2023-12-10 Added ADC controlled LP filter to delay
2023-12-15 Working on USB failing under optimise level O1
    [AudioCodec.cpp, CDCHandler.cpp, Delay.cpp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]
2023-12-15 Work on optimising phaser filter calculations
2023-12-20 Fixes to web serial editor; mix levels for effects and delay
    [CDCHandler.cpp, Delay.cpp, EffectManager.cpp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]
2023-12-21 Reorganised delay samples for better cache locality
2023-12-21 Started adding framework for flanger code
2024-01-16 Moved effect sample buffer to effectManager class for shared access
2024-01-17 RingMod octave down now LP filtered
2024-01-18 Added switch to change between octave/ringmod; Updated web editor for dynamic check boxes
2024-01-20 Clocked delay working; fixes to flanger
    [AK4619_DevBoard.kicad_sch]
2024-01-20 Fixed buffer overrun in flanger
    [Flanger.cpp]
2024-01-21 Phaser filter count can be set to any number between 1 and 16
    [QuadMod.kicad_sch]
2024-01-21 Implemented constant power effect/delay mix controls
2024-01-22 Fixed bug in flanger sample interpolation
    [EffectManager.cpp, Flanger.cpp, main.cpp]
2024-01-23 Started roughing out panel design
    [QuadMod.kicad_sch, QuadMod_Panel.kicad_pcb]
2024-01-25 Work on panel
    [QuadMod_Panel.kicad_pcb]
2024-01-25 Updates to Panel
    [QuadMod_Panel.kicad_pcb]
2024-01-26 First draft of panel completed
    [QuadMod_Panel.kicad_pcb]
2024-01-27 Cleaned up schematic
    [QuadMod Components.kicad_pcb, QuadMod Components.kicad_sch, QuadMod_Panel.kicad_pcb]
2024-01-27 Started component layout
    [QuadMod Components.kicad_pcb, QuadMod Components.kicad_sch, QuadMod_Panel.kicad_pcb]
2024-01-28 Preliminary component routing
    [QuadMod Components.kicad_pcb, QuadMod Components.kicad_sch]
2024-01-29 First pass signal routing of component board
    [QuadMod Components.kicad_pcb, QuadMod Components.kicad_sch]
2024-01-30 First draft of power routing completed
    [QuadMod Components.kicad_pcb, QuadMod Components.kicad_sch]
2024-01-30 Basic layout complete
    [QuadMod Components.kicad_pcb, QuadMod Components.kicad_sch]
2024-01-31 First draft of control board
    [QuadMod Components.kicad_pcb, QuadMod Components.kicad_sch, QuadMod_Controls.kicad_pcb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]
2024-01-31 Started adding additional clock LED
    [QuadMod Components.kicad_pcb, QuadMod Components.kicad_sch, QuadMod_Controls.kicad_pcb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]
2024-02-01 Clean up of schematics and PCBS
    [QuadMod Components.kicad_pcb, QuadMod Components.kicad_sch, QuadMod_Controls.kicad_pcb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]
2024-02-02 Draft Gerber Creation
    [QuadMod Components-B_Cu.gbr, QuadMod Components-B_Mask.gbr, QuadMod Components-B_Paste.gbr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]
2024-02-04 Updated Production Gerbers; attempts to get USB working with O1 optimisation
    [QuadMod Components-B_Cu.gbr, QuadMod Components-B_Mask.gbr, QuadMod Components-B_Paste.gbr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]
2024-03-03 Configured and tested clock and adc
2024-03-03 USB and Audio Codec SPI working
2024-03-03 Audio codec output tested and working
    [QuadMod Components.kicad_sch]
2024-03-03 Audio channels 3 and 4 working; Added LED PWM
2024-03-04 All codec inputs tested after board rework on PC1
    [AudioCodec.cpp, initialisation.cpp]
2024-03-05 Updated GpioPIn.h; basic delay LED working
    [QuadMod Components.kicad_sch]
2024-03-06 Implemented effect switching
    [QuadMod Components.kicad_sch]
2024-03-06 Phaser displays modulation LFO on LED
2024-03-06 Refactored ADC mappings
2024-03-07 Code cleanup; started dubugging crackles on flanger
    [AudioCodec.cpp, CDCHandler.cpp, Delay.h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]
2024-03-07 Added flanger ADC smoothing
2024-03-07 ADC smoothing; Delay LED fades out
